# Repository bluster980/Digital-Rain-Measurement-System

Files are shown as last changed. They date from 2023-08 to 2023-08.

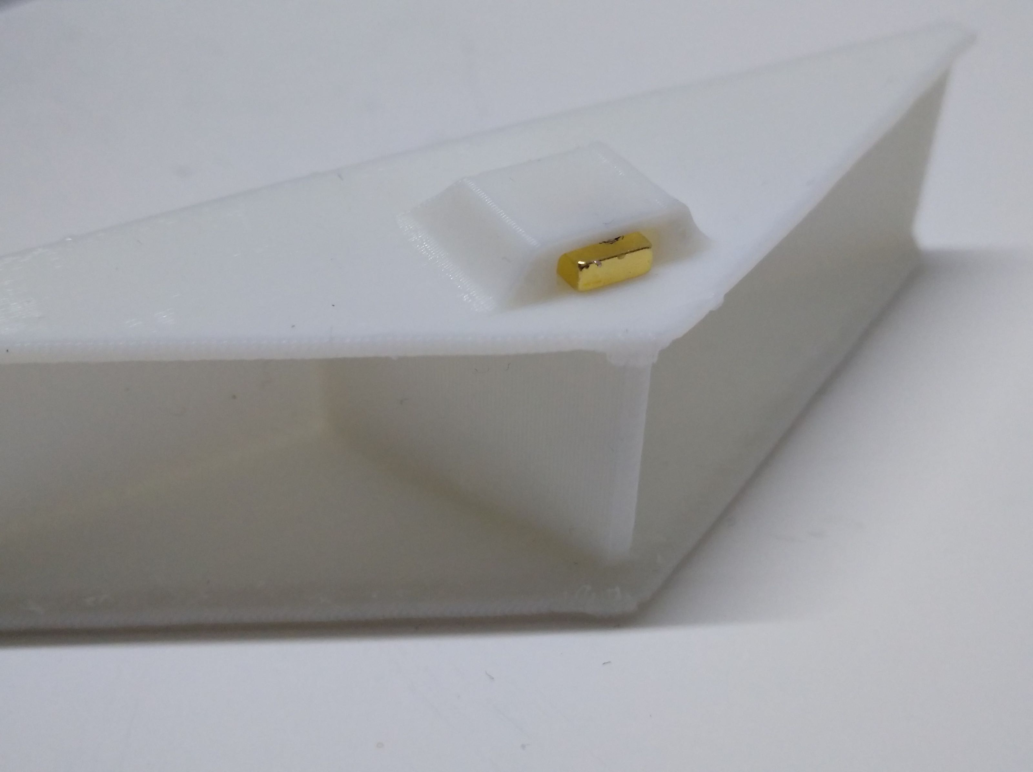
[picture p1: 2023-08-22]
design_files/Alternate_Designs/Tipping_Bucket_Rain_Gauge_for_HT_DN_110_pipe/images/IMG_20190714_002749_web.jpg

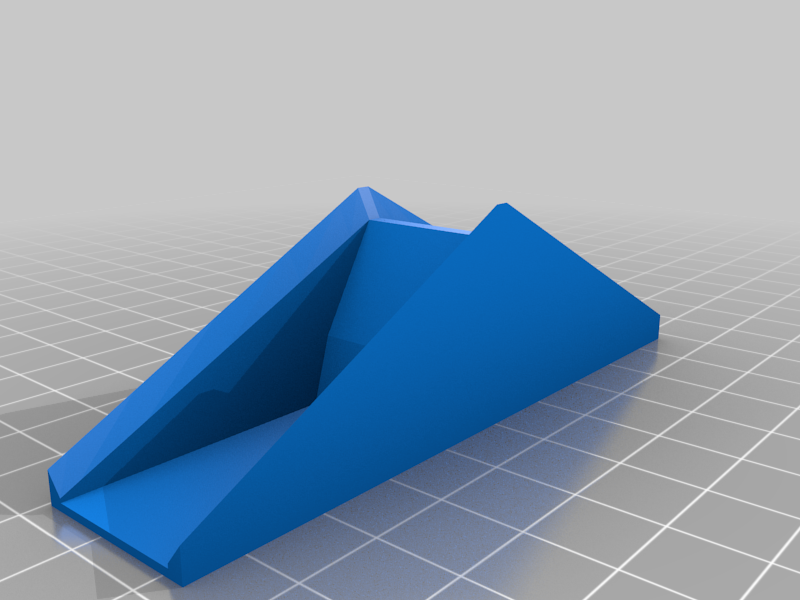
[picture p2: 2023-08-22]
design_files/Alternate_Designs/Tipping_Bucket_Rain_Gauge_for_HT_DN_110_pipe/images/Seesaw.png

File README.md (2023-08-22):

# Digital Rain Measurement System

## Introduction

Rainfall measurement is a crucial aspect of various fields such as forestry, hydrology, and more. This project introduces a digital rain measurement system that replaces traditional analog methods with a more convenient and accurate approach.

## Motivation

The motivation behind this project stems from the need for accurate and efficient rainfall measurements. Traditional rain gauges require manual data logging and are prone to errors. The aim of this project is to leverage modern technology to enhance the accuracy and convenience of rainfall measurement.

## Working Principle

The digital rain measurement system utilizes a tipping bucket mechanism. Rainwater accumulates on the funnel and gradually tips the bucket. When a certain amount of water collects on one side of the bucket, it tips, releasing water through holes. A sensor detects each tip and increments a counter variable. After rainfall stops, the microcontroller calculates the total count, which is then converted to rainfall volume.

## Technical Problems Faced

During the development of the project, several technical challenges were encountered and addressed:
- Issue with 3D printed bucket: Replaced with a newly printed model to ensure smooth tipping.
- Load balancing problem: Solved by applying uniform loads to both sides of the bucket.
- Water retention in the bucket: Addressed with various solutions like oiling, aluminum foil, and wax coating.
- Loose wiring causing inaccurate readings: Replaced with firm wires to ensure reliable sensor data.

## Possible Improvements

Several improvements can be made to enhance the project's accuracy and usability:
- Consider using stainless steel or suitable metal for better load balancing.
- Explore manufacturing techniques to reduce errors caused by 3D printing.
- Implement a design that expels all water after tipping.
- Integrate cloud connectivity to transmit collected data for remote monitoring.

## Future Scope

The digital rain measurement system holds promising potential for the future:
- Convenience: Technologically advanced lifestyle aligns with the system's ease of use.
- Remote Monitoring: Eliminates the need to physically travel to isolated areas for measurements.
- Real-time Measurements: Measurements can be taken during rainfall without waiting for it to stop.
- Minimal Maintenance: Requires less maintenance and offers more accurate results.

## References

1. Tipping bucket rain gauge design, designed in FreeCAD. [Link](https://www.printables.com/model/247135-tipping-bucket-rain-gauge)
2. Borah, A., & Instructables. Arduino rain gauge calibration. [Link](https://www.instructables.com/Arduino-Rain-Gauge-Calibration/)
3. Tipping bucket rain gauge. [Link](https://create.arduino.cc/projecthub/Bcjams/tipping-bucket-rain-gauge-75c393)
4. Tipping bucket rain gauge: 3D model: Mckillnm. [Link](https://thangs.com/designer/mckillnm/3d-model/Tipping%20Bucket%20Rain%20Gauge-212166)
5. Farmhackunsw, & Instructables. Nodemcu Hall Effect Rain Gauge. [Link](https://www.instructables.com/NodeMCU-Hall-Effect-Rain-Gauge/)
6. Tipping bucket rain gauge. [Link](https://stevenswater.com/products/tipping-bucket-rain-gauge/)
7. Stainless Steel Tipping Bucket Rain Gauge. [Link](https://www.indiamart.com/proddetail/stainless-steel-tipping-bucket-rain-gauge-26440381288.html)
8. Speed measuring counter sensor groove coupler module. [Link](https://www.techtonics.in/speed-measuring-counter-sensor-groove-coupler-module)
9. Borah, A., & Instructables. Arduino rain gauge calibration. [Link](https://www.instructables.com/Arduino-Rain-Gauge-Calibration/)
10. What is a tipping bucket rain gauge, and how does it work? [Link](https://www.instrumentchoice.com.au/news/what-is-a-tipping-bucket-rain-gauge-and-how-does-it-work)

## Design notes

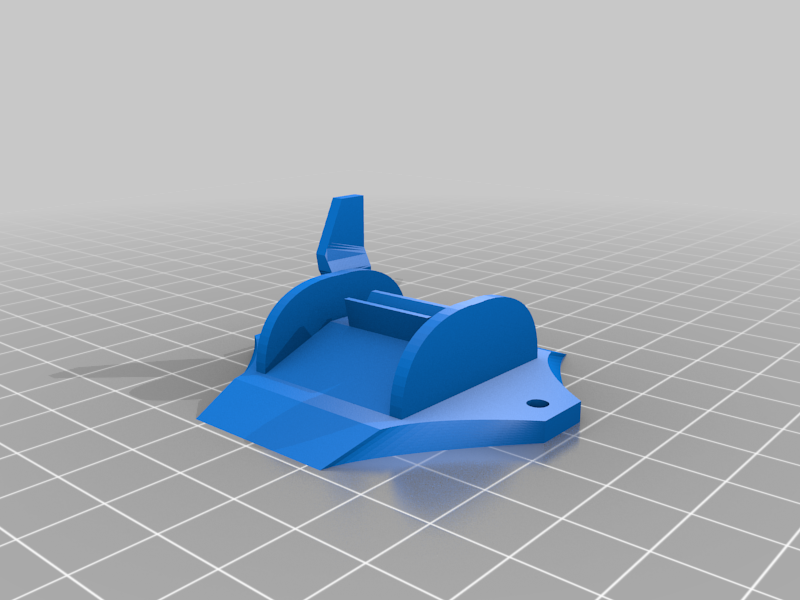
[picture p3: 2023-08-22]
design_files/Alternate_Designs/Tipping_Bucket_Rain_Gauge_for_HT_DN_110_pipe/images/Baseplate.png

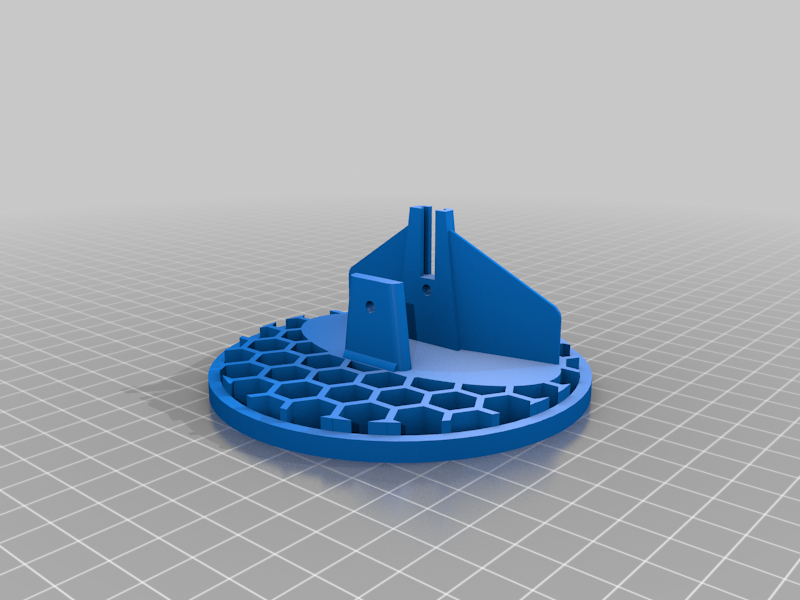
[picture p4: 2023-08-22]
design_files/Alternate_Designs/Tipping_bucket_rain_gauge_01/images/pad.png

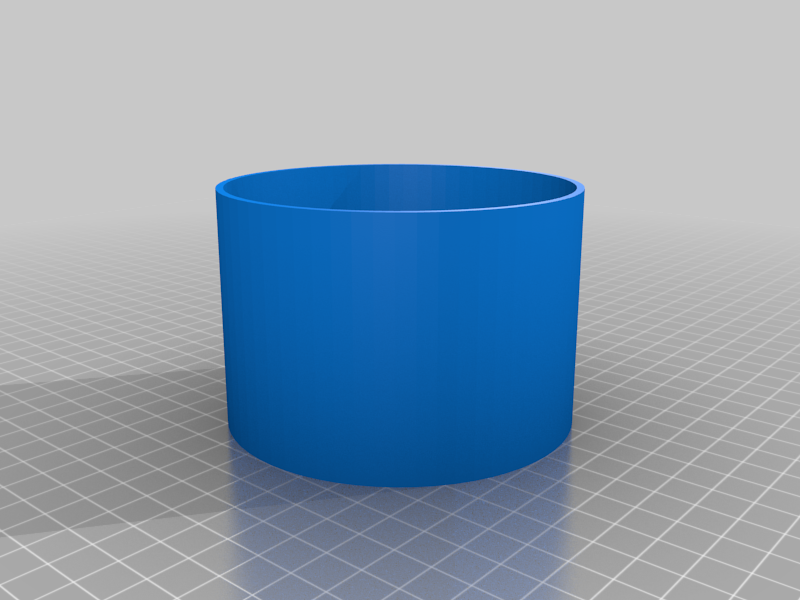
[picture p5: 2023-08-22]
design_files/Alternate_Designs/Tipping_bucket_rain_gauge_01/images/body.png

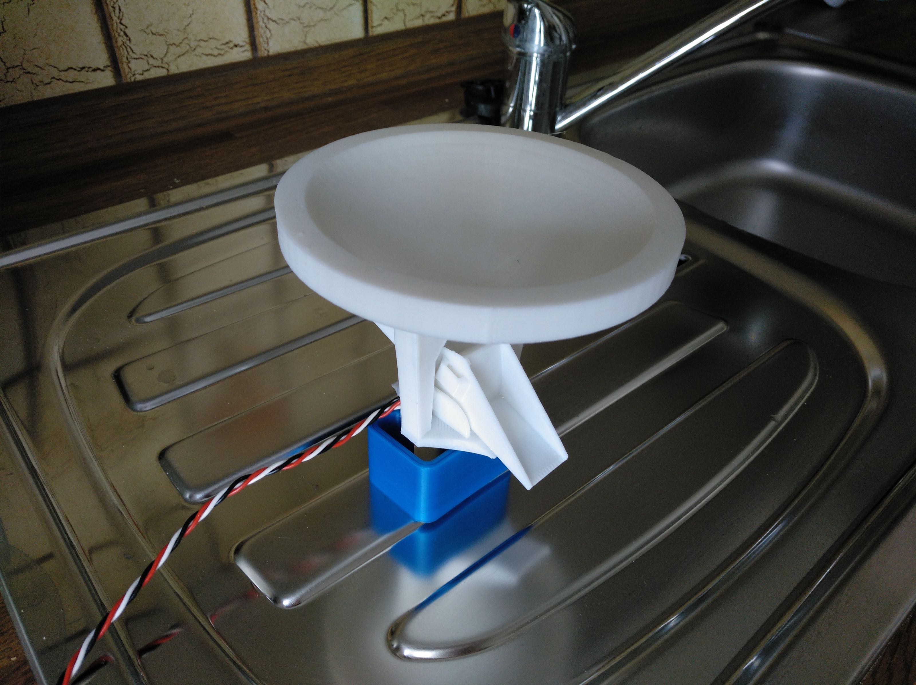
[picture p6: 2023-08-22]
design_files/Alternate_Designs/Tipping_Bucket_Rain_Gauge_for_HT_DN_110_pipe/images/IMG_20190714_142952_web.jpg

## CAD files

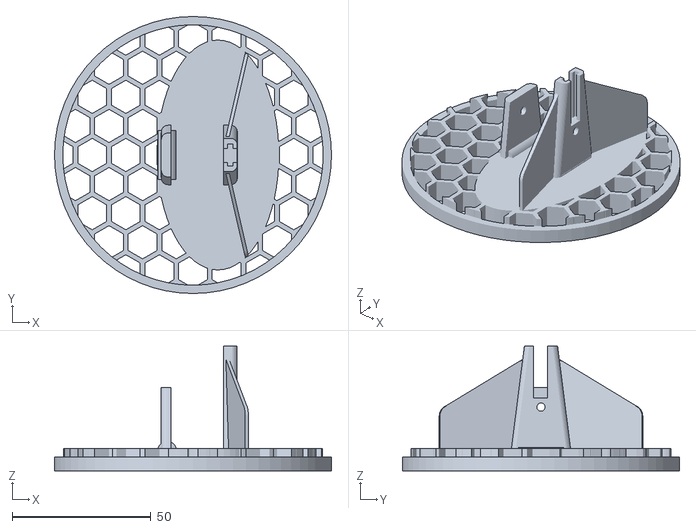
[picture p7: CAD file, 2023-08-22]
design_files/Alternate_Designs/Tipping_bucket_rain_gauge_01/files/pad.stl
100.0 x 100.0 x 45.0

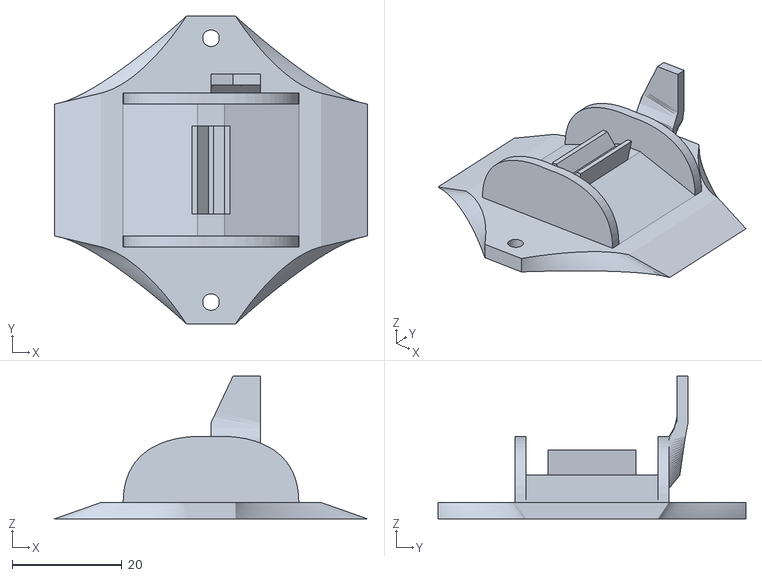
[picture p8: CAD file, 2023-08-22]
design_files/Alternate_Designs/Tipping_Bucket_Rain_Gauge_for_HT_DN_110_pipe/files/Baseplate.stl
57.0 x 56.0 x 26.0

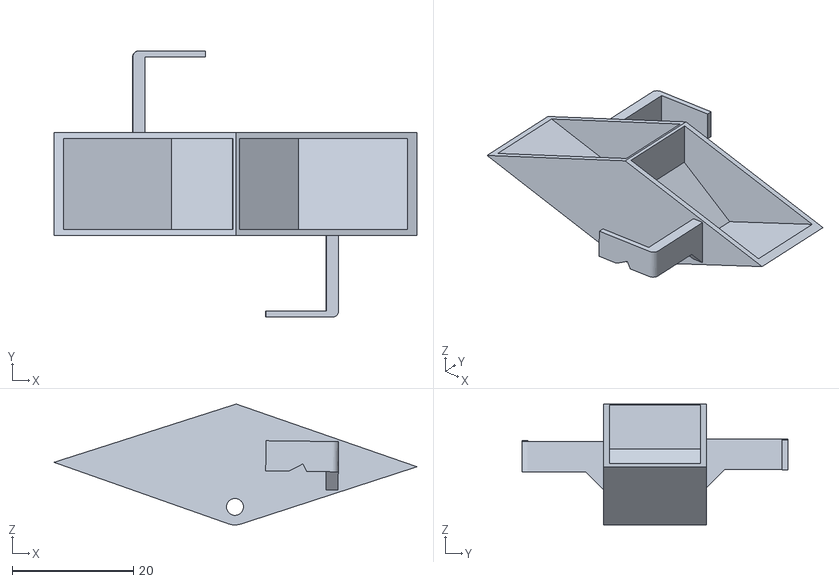
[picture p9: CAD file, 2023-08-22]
design_files/Our_Project_Designs/Bucket.stl
60.0 x 44.0 x 20.0

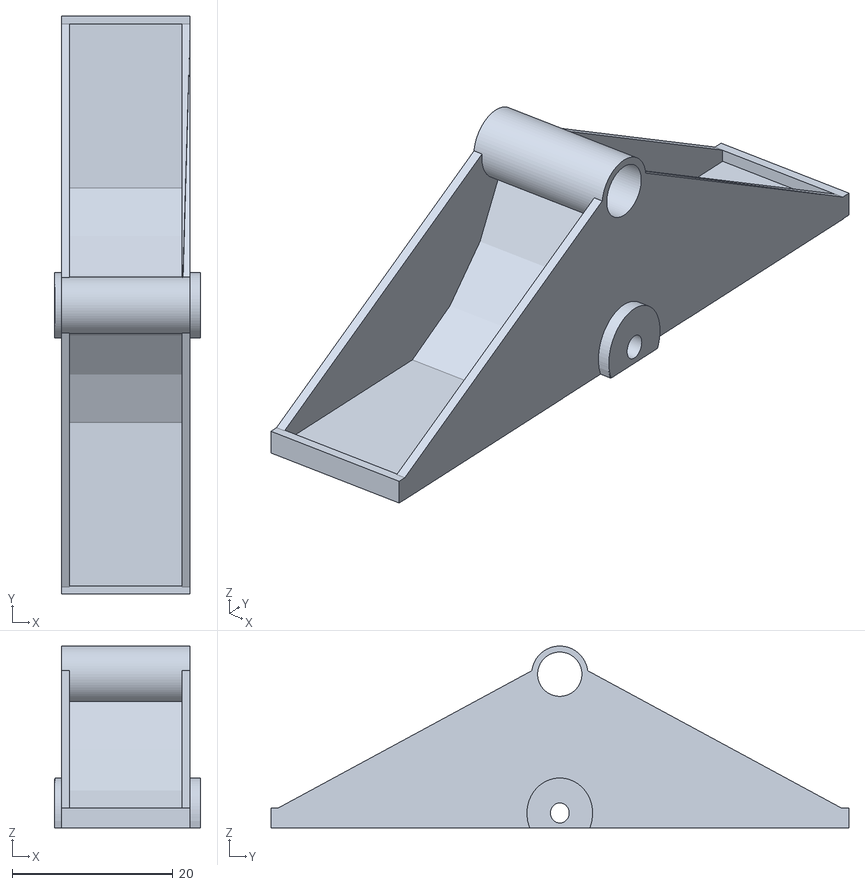
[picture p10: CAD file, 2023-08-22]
design_files/Alternate_Designs/Tipping_bucket_rain_gauge_01/files/bucket.stl
18.2 x 71.9 x 22.6

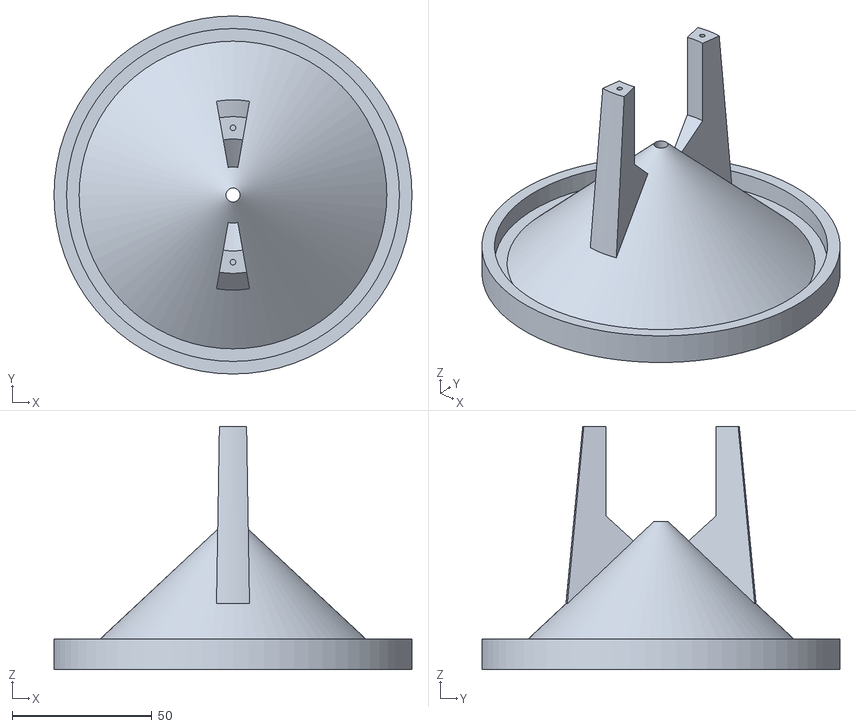
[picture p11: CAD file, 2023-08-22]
design_files/Alternate_Designs/Tipping_Bucket_Rain_Gauge_for_HT_DN_110_pipe/files/FunnelHTDN110.stl
128.0 x 128.0 x 87.0

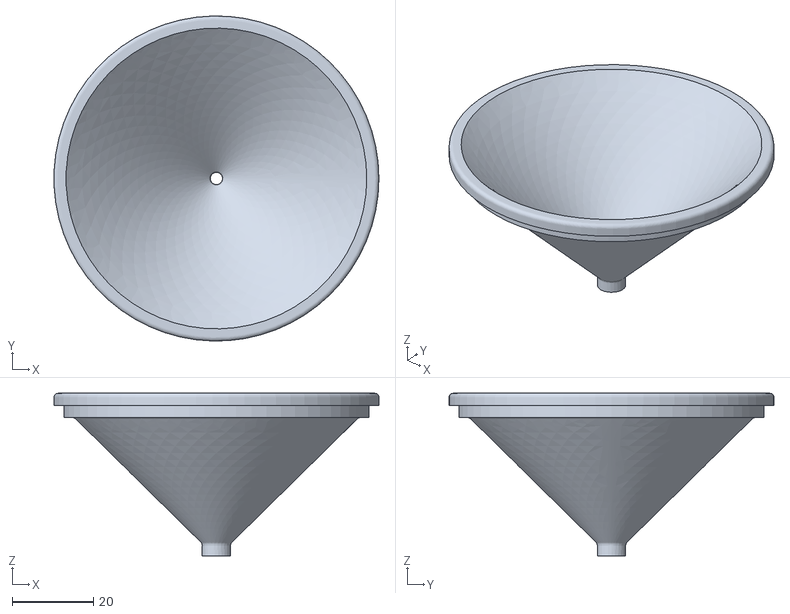
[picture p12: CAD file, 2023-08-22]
design_files/Our_Project_Designs/Funnel.stl
80.0 x 80.0 x 40.0

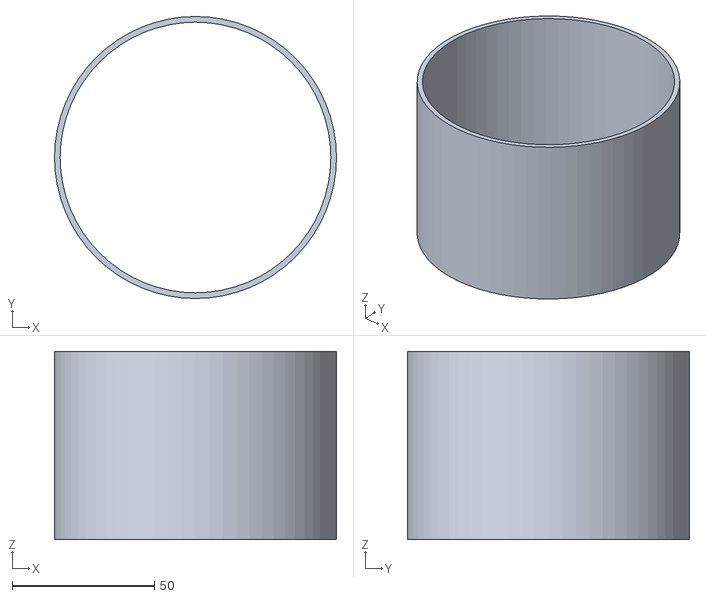
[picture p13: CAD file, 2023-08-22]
design_files/Alternate_Designs/Tipping_bucket_rain_gauge_01/files/body.stl
99.0 x 99.0 x 66.0

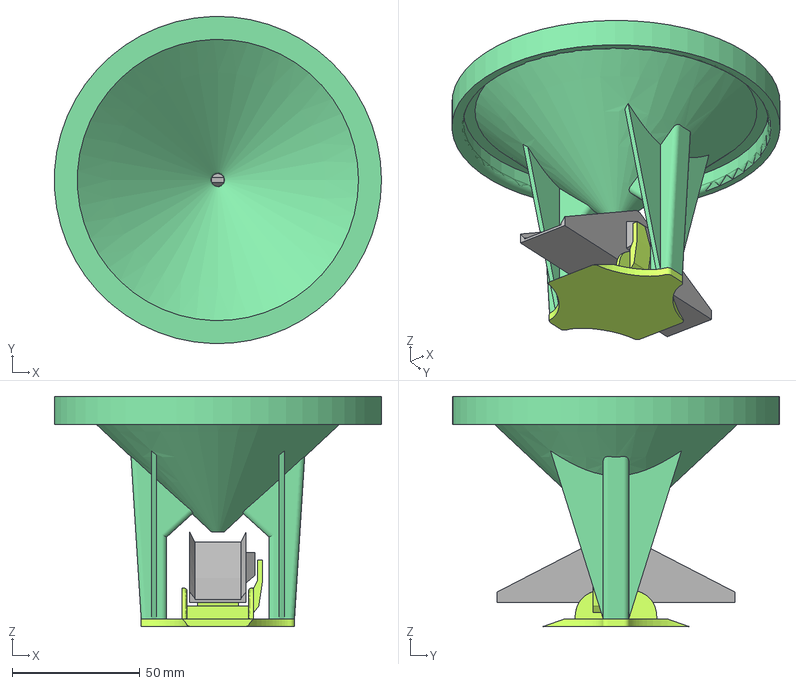
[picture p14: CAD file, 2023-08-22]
design_files/Alternate_Designs/Tipping_Bucket_Rain_Gauge_for_HT_DN_110_pipe/files/Rain_Gauge_Public_WIP.FCStd
127.9 x 127.9 x 90.0 mm
Funnel
Baseplate001
Seesaw

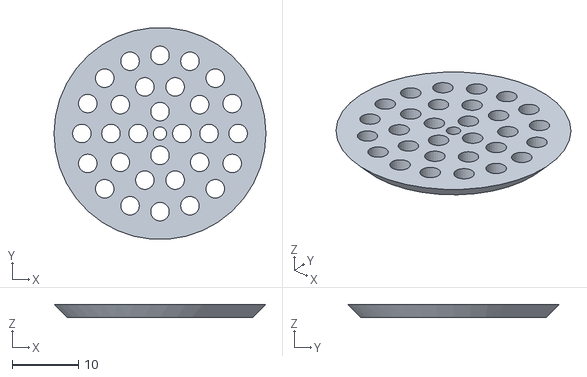
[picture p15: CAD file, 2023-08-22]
design_files/Our_Project_Designs/Filter.stl
32.0 x 31.9 x 2.00

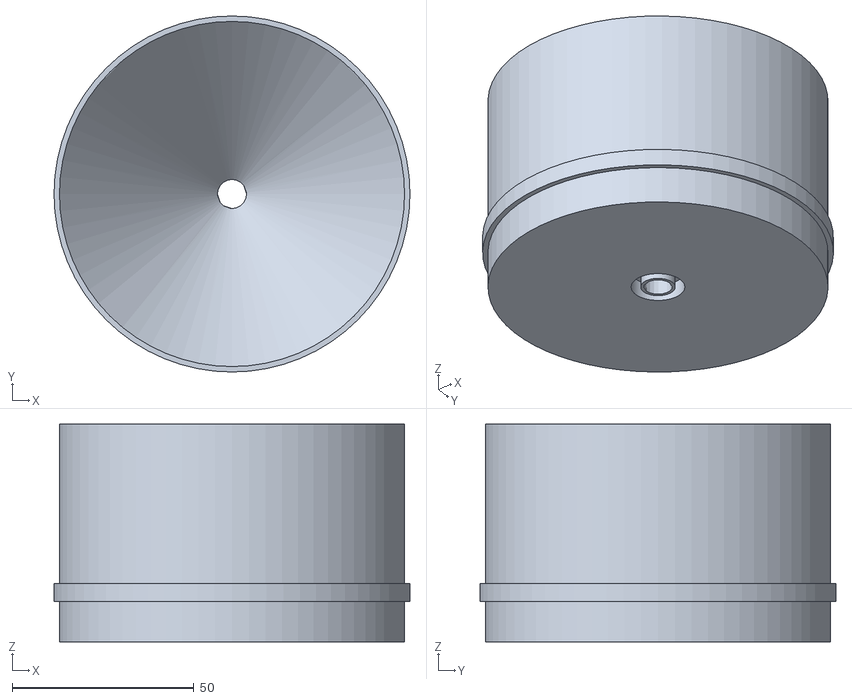
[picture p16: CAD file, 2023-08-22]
design_files/Alternate_Designs/Tipping_bucket_rain_gauge_01/files/funnel.stl
98.0 x 98.0 x 60.0

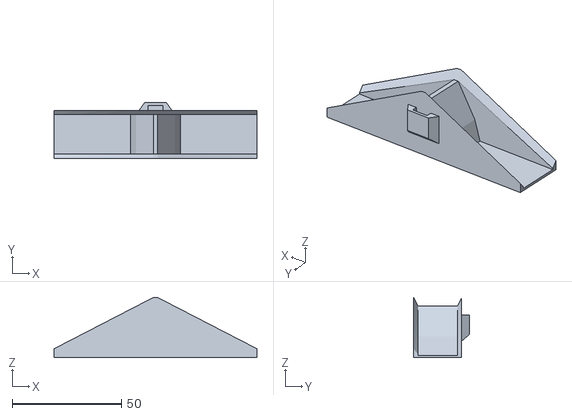
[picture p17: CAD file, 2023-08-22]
design_files/Alternate_Designs/Tipping_Bucket_Rain_Gauge_for_HT_DN_110_pipe/files/Seesaw.stl
93.0 x 25.5 x 27.5

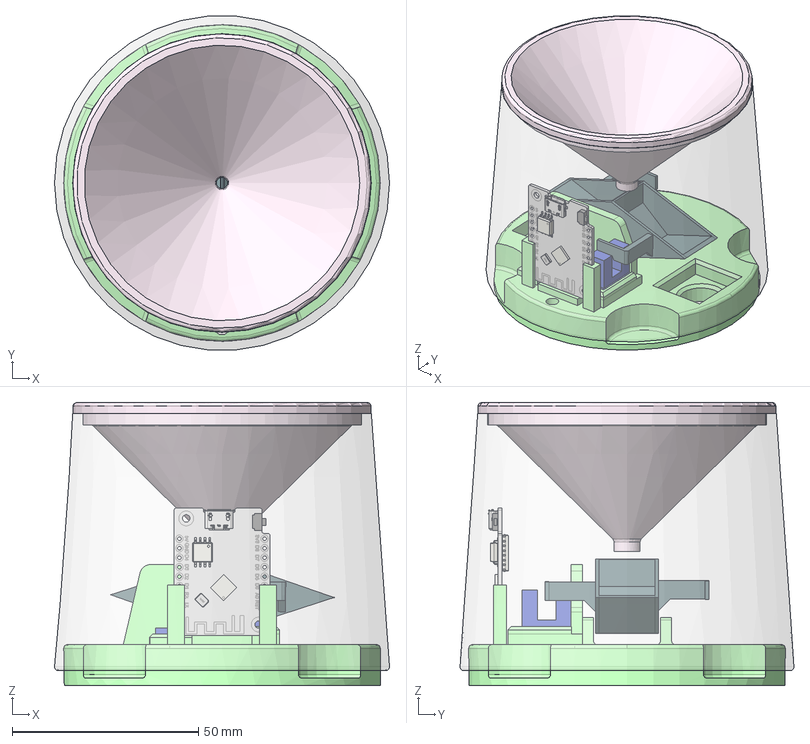
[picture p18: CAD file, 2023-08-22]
design_files/Our_Project_Designs/Rain_Guage.FCStd
89.9 x 89.6 x 76.0 mm
Base
Case
Sensor
WEMOS_D1_MINI_V_3_0_0_PCB_180112_01
WEMOS_D1_MINI_V_3_0_0_PUSH_BUTTON_180111_01
QFN_32_1EP_5x5mm_Pitch0_5mm_step1_01
SOIJ_8_5_3x5_3mm_Pitch1_27mm_step1_01
ABM8_STEP1_01
_050170001_stp1_01
SOIC_16_3_9x9_9mm_Pitch1_27mm_step1_01
Funnel
Bucket

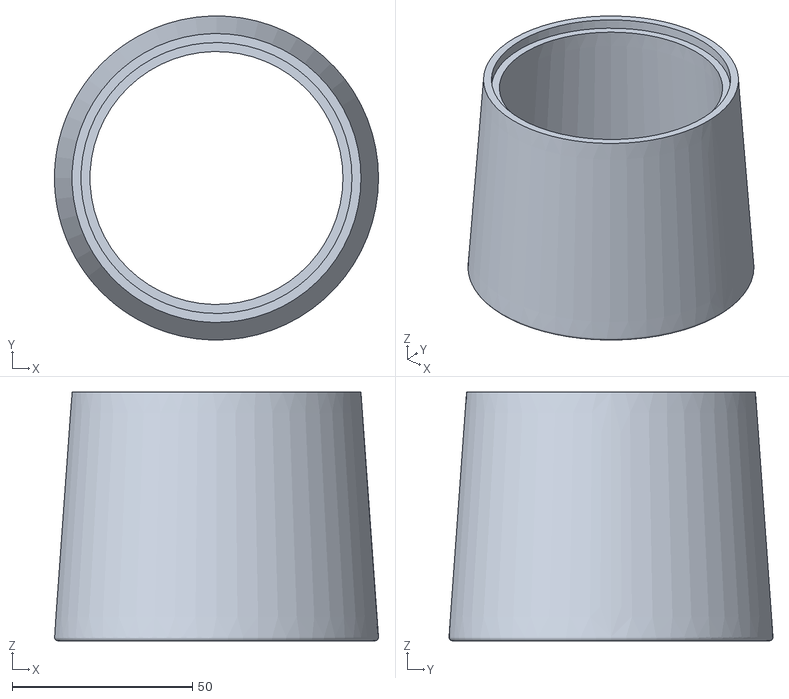
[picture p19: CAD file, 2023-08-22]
design_files/Our_Project_Designs/Case.stl
89.9 x 89.9 x 69.0

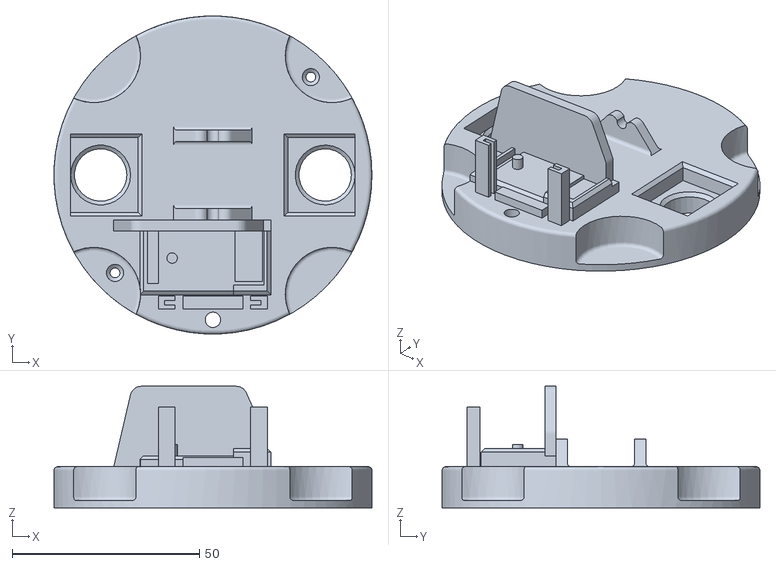
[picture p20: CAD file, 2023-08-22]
design_files/Our_Project_Designs/Base.stl
85.0 x 85.0 x 32.5

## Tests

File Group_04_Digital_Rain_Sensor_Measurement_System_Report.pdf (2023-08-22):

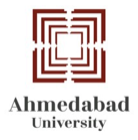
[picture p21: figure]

School of Engineering and Applied Science (SEAS), Ahmedabad University Sensors, Instrumental and Experimentation and Embedded Systems Design (ENR305 and ECE302)

### Project - Digital Rain Measurement System Report - Group 4

## Section - 3 & 2

Monsoon Semester - 2022

## Submitted to faculty: Prof. Sanket Patel

## Students Details:

Name | Enrollment Number
Dhruvam Bhalodiya | AU2040041
Heet Dedakiya | AU2040150
Jatin Parmar | AU2040118
Neilay Bhatt | AU2040254
Rucha Sanghvi | AU2040012

### 1. Introduction:

Background:

The water cycle cannot exist without rain, which is also the planet's primary source of freshwater. Simple terms, rain is precipitation in the form of water droplets that are heavy enough to fall to the ground due to the condensation of water vapor. Measurement of rainfall is essential for many fields, including forestry, hydrology, and others.

Motivation:
Since the time of the ancient Greeks, people have kept track of the amount of rain that has fallen, and the first measurements were performed using a rain gauge. This instrument was created in India in the fourth century. The simplest rain gauges consisted of a plain cylinder with markings to track the amount of precipitation over time. And they deliver readings that are extremely accurate. But the rain measurement system has evolved over time, just as everything else does. Traditional systems require you to manually log data yourself, which increases the likelihood of errors. In order to find out the readings, you must also go to the location where the cylinders are housed. And in some isolated regions, it is difficult. Additionally, you must wait until the rain stops before taking precise measurements. It also needs a lot of maintenance. The computerized rain measurement method was taken into consideration.

### 2. Literature Review:

These are the alternate designs from which we took reference from and these are used at industrial level. Existing Model 1:

Tipping bucket rain gauge:

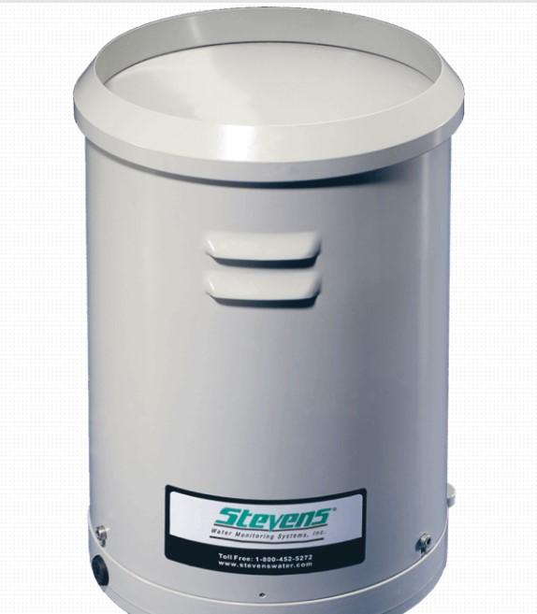
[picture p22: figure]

The bucket tips when precipitation of 0.01″, 0.2 mm, 0.5 mm or 1.0 mm has been collected. Each tip activates a reed switch closure which is detected by a data logger and/or telemetry system.
It’s also available with a larger collector measuring 11.1″ (282.8 mm) in diameter.

Receiver | 200mm (8 inch) or 282.8 mm (11.1 inch) diameter with machined aluminum rim
Sensitivity | One tip at 0.2, 0.5, 1.0 mm or 0.01 inch
Measurements | Range: 0-700 mm/hour Accuracy: ± 2% 25-500 mm/hour, ± 1 tip from 1-25 mm/hour
Sensor | Tipping bucket with siphon
Siphon | 0.4mm capacity of rainfall - made from brass with a non-hygroscopic outer body
Contacts | Type: dual reed-switch (make contact), momentary Rating:12 VA (0.5 amp max) Duration: 0.1 second
Physical dimensions | Height x diameter: 342 mm (13.5") x 229 mm 9" Weight: 3 kg (6.6 lbs)
Bucket | Chrome plated, injected molded non-hygroscopic ABS balanced ± 0.05 gms
Base | Die-cast aluminum
Mounting holes | Three (3) 10mm diameter mounting holes
Drain fittings | Able to attach 12 mm inside diameter tubing, to catch rainfall after passing through buckets
Pivots | Ground sapphire pivots with stainless steel shaft
Insect covers | Stainless steel mesh on all openings to prevent insects from entering gauge

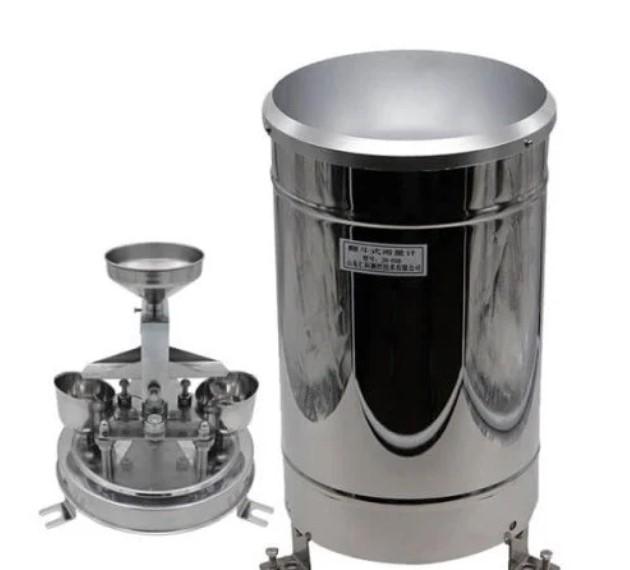
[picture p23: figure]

Existing Model 2:

Industrial Level(cost: 15600):
It is a mechanical bistable structure. When one chamber receives water, the other chamber is waiting. When it rains, the rainwater collected by the water receiving port enters the metering bucket through the funnel. When the volume of the received rainwater reaches the predetermined value of 0.2mm, the chamber will overturn due to gravity and be waiting, and the other chamber will be in a state of receiving water

The stainless steel rain gauge is recognized to be the standard for measuring rainfall and other precipitation in hydrological and environmental testing. The internal tipping bucket structure provides high accuracy in various rainfall intensity ranges. Stainless Steel Rain Gauge Parameters Rain bearing diameter: φ200mm
The sharp angle of cutting edge: 40 45°
Rain intensity range: 0mm 4mm/min (allowable maximum rain intensity 8mm/min)
Power supply range: 4.5~30V
Maximum power consumption: 0.24W
Working temperature: 0 50
Working humidity: <95%(40)

Existing Model 3:

The 260-2500 Tipping Bucket Rain Gauges are dependable instruments used for measuring precipitation. Rainfall entering the 8" or 12" funnel collector is directed to the tipping bucket assembly. When an incremental amount of precipitation has been collected, the bucket assembly tips and activates a magnetic reed switch.

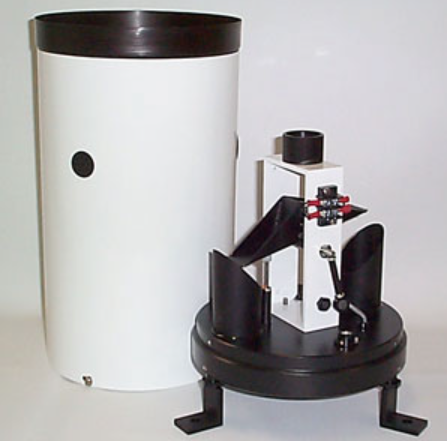
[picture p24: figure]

- Capacity: Unlimited
- Orifice:
- 260-2500: 8" (20 cm)
- 260-2500-12: 12" (30 cm)
- Calibration: 0.01", 0.25 mm, 0.5 mm, 1 mm
- Accuracy: ±1% at 2"/hr
- Output: 0.1 second switch closure
- Contact rating: 3 watts, 0.25 amps, 24 Vdc
- Size

- 260-2500: 8" x 17"
- 260-2500-12: 12" x 20"
- Weight/Shipping
- 260-2500: 7 lb/12 lb
- 260-2500-12: 14 lb/18 lb

### 3. Methodology:

Product details:
Product Specifications:
Our product contains a funnel of 8cm diameter (The standard size of the funnel is 16 to 21 cm), a tipping bucket, a base and a case. The tipping bucket is fixed in the base and placed in the case in such a way that the gap between the tipping bucket and the funnel’s tip is 0.98mm.
Circuit Diagram:

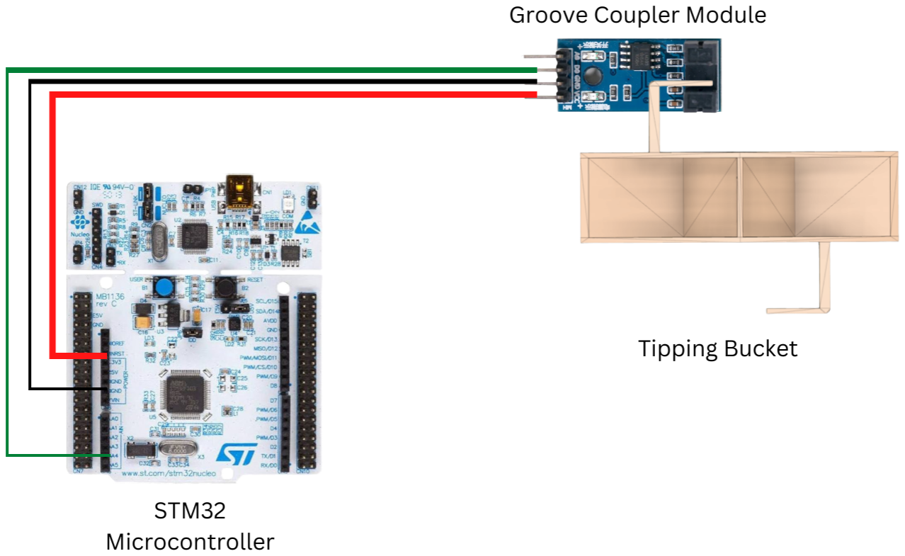
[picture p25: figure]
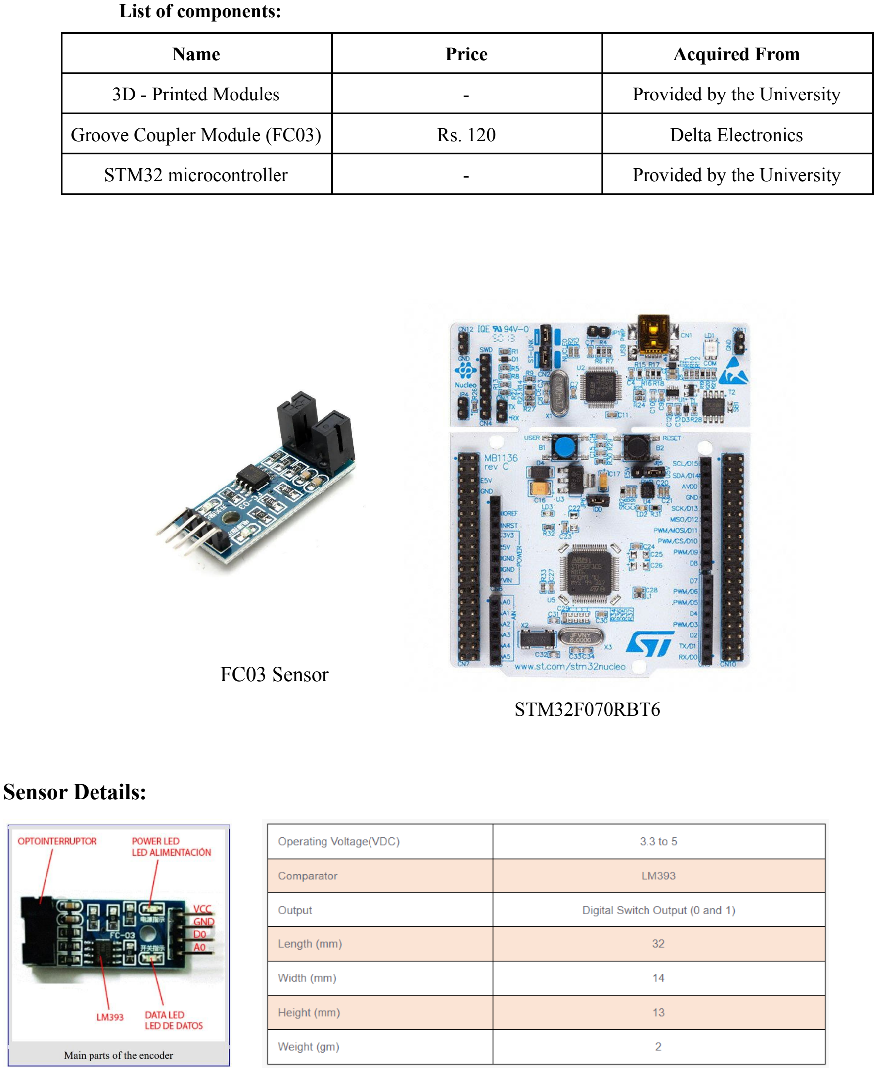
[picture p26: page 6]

List of components:

Name | Price | Acquired From
3D - Printed Modules | - | Provided by the University
Groove Coupler Module (FC03) | Rs. 120 | Delta Electronics
STM32 microcontroller | - | Provided by the University

FC03 Sensor
STM32F070RBT6

Sensor Details:

3D - Design Of Modul’s Components

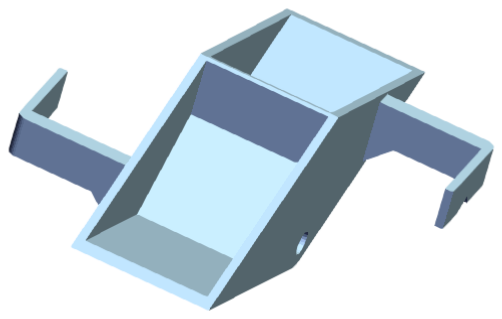
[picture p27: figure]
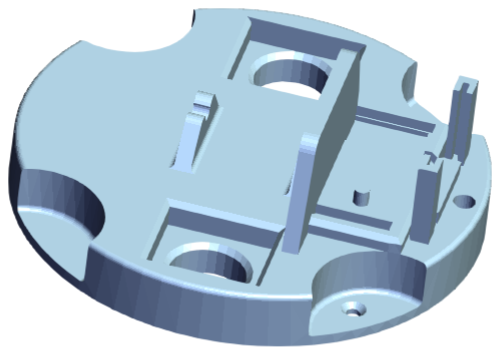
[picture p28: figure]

Base | Bucket

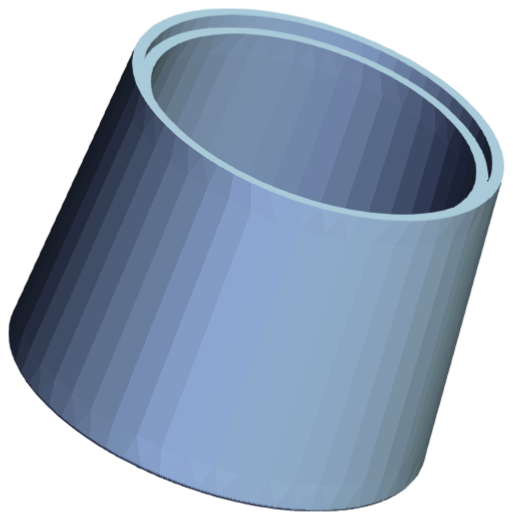
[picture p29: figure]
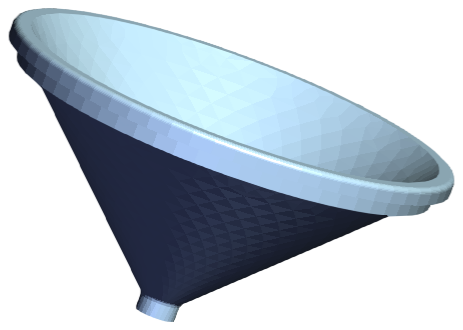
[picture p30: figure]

Case | Funnel


## Mounting

Working of the product:
This digital rain measurement system will measure the amount of rain digitally rather than the traditional analog methods. Rain drops will accumulate on the top of the funnel and then steadily drop on the tipping bucket. When a certain amount of water will gather at one side of the bucket, it will tip and at that moment the water will flow out from the holes and the sensor will read the signal and increment the counter variable which is initialized to 0. Later when the rain is stopped, the microcontroller would have the total number of counts, which will then be multiplied to volume per count to get the volume of the rain. We need to have 3-4 modules of the product in a particular area to get an accurate measurement of rain.

Experimentation:
We experimented with the working of our product in a series of experiments. We poured many samples of 50 mL, 100 mL and 200 mL water and saw what was the output. Based on that we calculated the volume per count and the error in measurement. We maintained an Excel spreadsheet to record our results. By doing these experiments, we got the volume per count to be around 5.238 mL/count. Thus getting the following equation.

volume in mL = count * 5. 238

volume in incℎes = volume in mL * 0. 0393


Technologies Used:
1) Fusion 360 for 3D printing.
2) FreeCAD for measuring dimensions.
3) STM32CubeMX and Keil μVision 5 for STM32F070RBT6 Microcontroller programming.

Code:
Only including variables and int main() part.

/* USER CODE BEGIN 0 */ int flag=1; float count=0; float rainAmt_mL=0; float rainAmt_inch=0; /* USER CODE END 0 */; int main(void) { /* USER CODE BEGIN 1 */; /* USER CODE END 1 */; HAL_Init();; /* USER CODE BEGIN Init */; /* USER CODE END Init */; /* Configure the system clock */ SystemClock_Config();; /* USER CODE BEGIN SysInit */; /* USER CODE END SysInit */; MX_GPIO_Init(); MX_USART2_UART_Init();

/* MCU Configuration--------------------------------------------------------*/

/* Reset of all peripherals, Initializes the Flash interface and the Systick. */

/* Initialize all configured peripherals */

/* USER CODE BEGIN 2 */; /* USER CODE END 2 */; /* Infinite loop */ /* USER CODE BEGIN WHILE */ while (1) { /* USER CODE END WHILE */; /* USER CODE BEGIN 3 */; count++;; rainAmt_mL=count*5.238; rainAmt_inch=rainAmt_mL*0.0393; flag=0;; flag=1;; } else {; } /* USER CODE END 3 */ }

if((HAL_GPIO_ReadPin(GPIOC, GPIO_PIN_1)) && flag)

HAL_GPIO_WritePin(GPIOA,GPIO_PIN_5,GPIO_PIN_SET);

else if(!HAL_GPIO_ReadPin(GPIOC, GPIO_PIN_1))

HAL_GPIO_WritePin(GPIOA,GPIO_PIN_5,GPIO_PIN_RESET);

### 4. Outcome:

The outcome of this project is measurement of rainfall by digital methods. We got the measurement of rain in Millilitres and inches. This project can replace the traditional analog way of measuring rainfall.

### 5. Technical problems faced:

We did face a few problems in our journey. First one was that our tipping bucket was not properly printed. We replaced that with a newly printed model of the bucket. It still wasn’t so smooth because it was 3D printed. Second problem was balancing the load of the tipping bucket. As the model was not perfectly printed, its load was not uniformly distributed and that arose the problems in tipping. We solved that problem by applying uniform loads on both sides of the bucket. Third problem was water remaining in the bucket. Due to our design and the plastic material, water remained stored in the bucket after the last tip. To solve that, we first tried oiling the inside of the bucket. Then we applied aluminum foil. But those two didn’t work out well. So at last, we applied wax on the inside which made the surface smooth. Still, very little amount of water would be left but we added that in our error analysis. Last problem was that our wiring was a little loose which sometimes created problems like the sensor calculated false values of counts. We replaced them with new firm wires. These were the technical problems we faced in our project.

### 6. Possible improvements:

The material used in our project is plastic. We can use stainless steel or any other suitable metal to make load balancing better. This project contains some errors due to 3D printed design, which can be reduced by manufacturing it and can be made more accurate for better results by taking more experiments and calculating accurate errors. The system can be modified which doesn’t store water and kicks all the water out. Also, we can send the data collected to the cloud for more convenience.

### 7. Future Scope:

Digital rain measurement system’s scope in the future is pretty good as it will be more convenient to use because of the technologised lifestyle. Additionally, one doesn't have to take a trip to the isolated areas to measure the rainfall. Also, we don’t have to wait for the rain to stop to measure the amount of rainfall. Also, it doesn’t need a lot of maintenance and gives more accurate results.

### 8. Conclusion:

Thus, in this project we applied our basic understanding of sensors and microcontrollers along with applying some mechanical knowledge for implementing hardware of our project. By doing so we were able to make a system that can be useful for measuring rainfall. This project also contributed to the increase of our knowledge of sensors, microcontrollers and different ways to measure rain.

### 9. References:

1. Tipping bucket rain gauge design, designed in FreeCAD. (n.d.). Retrieved December 6, 2022, from https://www.printables.com/model/247135-tipping-bucket-rain-gauge
2. Borah, A., & Instructables. (2019, May 09). Arduino rain gauge calibration. Retrieved December 6, 2022, from https://www.instructables.com/Arduino-Rain-Gauge-Calibration/
3. Tipping bucket rain gauge. (n.d.). Retrieved December 6, 2022, from https://create.arduino.cc/projecthub/Bcjams/tipping-bucket-rain-gauge-75c393
4. Tipping bucket rain gauge: 3D model: Mckillnm. (n.d.). Retrieved December 6, 2022, from https://thangs.com/designer/mckillnm/3d-model/Tipping%20Bucket%20Rain%20Gauge-212166
5. Farmhackunsw, & Instructables. (2018, May 30). Nodemcu Hall Effect Rain Gauge. Retrieved December 6, 2022, from https://www.instructables.com/NodeMCU-Hall-Effect-Rain-Gauge/
6. Tipping bucket rain gauge. (2019, November 05). Retrieved December 7, 2022, from https://stevenswater.com/products/tipping-bucket-rain-gauge/
7. Stainless Steel Tipping Bucket Rain Gauge. (n.d.). Retrieved December 7, 2022, from https://www.indiamart.com/proddetail/stainless-steel-tipping-bucket-rain-gauge-26440381288.ht ml (https://www.indiamart.com/proddetail/stainless-steel-tipping-bucket-rain-gauge-26440381288.html)
8. Speed measuring counter sensor groove coupler module. (n.d.). Retrieved December 7, 2022, from https://www.techtonics.in/speed-measuring-counter-sensor-groove-coupler-module
9. Borah, A., & Instructables. (2019, May 09). Arduino rain gauge calibration. Retrieved December 7, 2022, from https://www.instructables.com/Arduino-Rain-Gauge-Calibration/
10. What is a tipping bucket rain gauge, and how does it work? (n.d.). Retrieved December 7, 2022, from
https://www.instrumentchoice.com.au/news/what-is-a-tipping-bucket-rain-gauge-and-how-does-i t-work (https://www.instrumentchoice.com.au/news/what-is-a-tipping-bucket-rain-gauge-and-how-does-it-work)

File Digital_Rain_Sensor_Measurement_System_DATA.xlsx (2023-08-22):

Experiment No. | Total Counts | Input Water(ml) | Output Water(ml) | Difference (calculation) | Water per Count(ml) | Difference(we got)
1 | 11 | 50 | 46 | 4 | 4.181818182 | 5
2 | 19 | 100 | 95 | 5 | 5 | 5
3 | 20 | 100 | 94 | 6 | 4.7 | 5
4 | 18 | 100 | 95 | 5 | 5.277777778 | 5
5 | 18 | 100 | 96 | 4 | 5.333333333 | 4
6 | 19 | 100 | 94 | 6 | 4.947368421 | 4.5
Average | 18.8 |  | 94.8 | 5.2 | 5.051695906 | 4.7
7 | 29 | 150 | 144 | 7 | 4.965517241 | 6
8 | 27 | 150 | 144 | 6 | 5.333333333 | 7
9 | 27 | 150 | 145 | 5 | 5.37037037 | 4
10 | 32 | 150 | 145 | 5 | 4.53125 | 4
11 | 29 | 150 | 146 | 8 | 5.034482759 | 4
Average | 28.8 |  | 144.8 | 6.2 | 5.046990741 | 5
 |  |  |  |  |  |  | no error in 100 ml
 |  |  |  |  |  |  | error of 0.33 in 150 ml exp
12 | 41 | 200 | 194 | 6 | 4.731707317 | 4.5
13 | 38 | 200 | 193 | 7 | 5.078947368 | 5
14 | 42 | 200 | 194 | 6 | 4.619047619 | 5
15 | 36 | 200 | 194 | 9 | 5.388888889 | 5
16 | 36 | 200 | 195 | 5 | 5.416666667 | 5
Average | 38.6 |  | 194 | 6.6 | 5.047051572 | 4.9
Second Prototype
17 | 19 | 100 | 95.6 | 4.4 | 5.031578947 | 4.4
18 | 19 | 100 | 96.3 | 3.7 | 5.068421053 | 3.7
19 | 18 | 100 | 96.4 | 3.6 | 5.355555556 | 3.6
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

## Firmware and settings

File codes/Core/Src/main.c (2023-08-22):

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
/* Includes ------------------------------------------------------------------*/
#include "main.h"

UART_HandleTypeDef huart2;

void SystemClock_Config(void);
static void MX_GPIO_Init(void);
static void MX_USART2_UART_Init(void);
/* USER CODE BEGIN 0 */
int flag=1;
float count=0;
float rainAmt_mL=0;
float rainAmt_inch=0;
/* USER CODE END 0 */

/**
  * @brief  The application entry point.
  * @retval int
  */
int main(void)
      {
  /* MCU Configuration--------------------------------------------------------*/

  /* Reset of all peripherals, Initializes the Flash interface and the Systick. */
  HAL_Init();

  /* Configure the system clock */
  SystemClock_Config();

  /* Initialize all configured peripherals */
  MX_GPIO_Init();
  MX_USART2_UART_Init();
  /* Infinite loop */
  /* USER CODE BEGIN WHILE */
  while (1)
  {
    /* USER CODE END WHILE */

    /* USER CODE BEGIN 3 */
		if((HAL_GPIO_ReadPin(GPIOC, GPIO_PIN_1)) && flag)
		{
			count++;
			HAL_GPIO_WritePin(GPIOA,GPIO_PIN_5,GPIO_PIN_SET);
			rainAmt_mL=count*5.238;
			rainAmt_inch=rainAmt_mL*0.0393;
			flag=0;
		}
		else if(!HAL_GPIO_ReadPin(GPIOC, GPIO_PIN_1))
		{
			flag=1;
		}
		else 
		{
			HAL_GPIO_WritePin(GPIOA,GPIO_PIN_5,GPIO_PIN_RESET);
		}
  }
  /* USER CODE END 3 */
}

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


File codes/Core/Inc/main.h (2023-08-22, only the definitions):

#define B1_Pin GPIO_PIN_13
#define B1_GPIO_Port GPIOC
#define B1_EXTI_IRQn EXTI4_15_IRQn
#define RCC_OSC32_IN_Pin GPIO_PIN_14
#define RCC_OSC32_IN_GPIO_Port GPIOC
#define RCC_OSC32_OUT_Pin GPIO_PIN_15
#define RCC_OSC32_OUT_GPIO_Port GPIOC
#define RCC_OSC_IN_Pin GPIO_PIN_0
#define RCC_OSC_IN_GPIO_Port GPIOF
#define RCC_OSC_OUT_Pin GPIO_PIN_1
#define RCC_OSC_OUT_GPIO_Port GPIOF
#define USART_TX_Pin GPIO_PIN_2
#define USART_TX_GPIO_Port GPIOA
#define USART_RX_Pin GPIO_PIN_3
#define USART_RX_GPIO_Port GPIOA
#define LD2_Pin GPIO_PIN_5
#define LD2_GPIO_Port GPIOA
#define TMS_Pin GPIO_PIN_13
#define TMS_GPIO_Port GPIOA
#define TCK_Pin GPIO_PIN_14
#define TCK_GPIO_Port GPIOA

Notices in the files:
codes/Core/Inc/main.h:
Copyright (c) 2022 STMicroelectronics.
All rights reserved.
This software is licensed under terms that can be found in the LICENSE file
